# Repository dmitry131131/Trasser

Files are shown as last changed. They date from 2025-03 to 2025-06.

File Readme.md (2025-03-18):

# Трассерная насадка для игры в страйкбол

## Содержание
1. [Цель проекта](#цель-проекта)
2. [Режимы работы](#режимы-работы)
3. [Принцип работы](#принцип-работы)
4. [Необходимые компоненты](#необходимые-компоненты)
5. [Используемые инструменты и станки](#используемые-инструменты-и-станки)
6. [Проблемы и трудности](#проблемы-и-трудности)
7. [Результат](#результат)

## Цель проекта

Разработка и изготовление компактной и надежной трассерной насадки для страйкбольного оружия, которая позволяет визуализировать полет шаров в условиях низкой освещенности. Насадка будет крепиться на ствол оружия на резьбу `M14-` и активироваться при выстреле, подсвечивая траекторию полета шаров с помощью ультрафиолетовых светодиодов. Управление устройством осуществляется на базе микроконтроллера `ATtiny13`, что обеспечивает минимальные габариты и энергопотребление.

## Режимы работы

Трассерная насадка будет иметь `3 режима` работы:
1. Ультрафиолетовая вспышка для подсветки шаров
2. Оранжевая вспышка на срезе ствола для имитации вспышки выстрела
3. Ультрафиолетовая вспышка и имитация вспышки выстрела

## Принцип работы

+ При выстреле страйкбольный шар проходит через ствол, пересекая луч инфракрасного датчика.
+ Датчик передает сигнал на микроконтроллер ATtiny13.
+ Микроконтроллер активирует ультрафиолетовые светодиоды на короткий промежуток времени (0.1 секунду).
+ Светодиоды подсвечивают шар внутри ствола, делая его видимым в темноте.
+ После завершения цикла устройство возвращается в режим ожидания для экономии энергии.

### Идейная схема реализации 

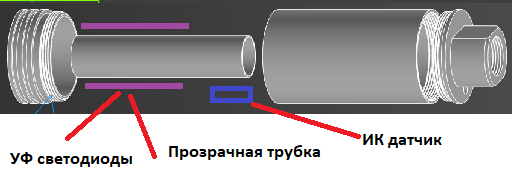
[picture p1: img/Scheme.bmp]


## Необходимые компоненты

Список необходимых компонентов:

### Электроника

| Компонент | Количество |
|---|---|
| Двухсторонний текстолит | 100x100mm |
| Микроконтроллер Attiny13 | 1шт |
| УФ светодиоды формата 5050 | 3шт |
| Оранжевые светодиоды 1206 | 3шт |
| SMD переменный резистор 20k | 1шт |
| SMD резистор 0805 10k | 1шт |
| SMD резистор 0805 1k | 4шт |
| SMD резистор 0805 4k | 1шт |
| SMD резистор 1206 20ОМ | 2шт |
| SMD резистор 1206 150ОМ | 1шт |
| SMD транзистор NPN bc817-40 | 2шт |
| SMD конденсатор 0603 0.1мкФ | 2шт |
| SMD конденсатор 0603 10мкФ | 1шт |
| Инфракрасный фотодиод 3мм | 1шт |
| SMD инфракрасный светодиод | 1шт |
| SMD светодиод 0603 красный | 1шт |
| SMD светодиод 0603 синий | 1шт |
| SMD микросхема TP4056 | 1шт |
| Li-ion аккумулятор 20/20/4мм 3.7В | 1шт |
| USB Type-C разъём | 1шт |
| SMD кнопка | 1шт |

### Корпус

| Компонент | Количество |
|---|---|
| Алюминиевая труба D = 35мм | 60мм |
| Прозрачная трубка D = 15мм | 60мм |
| Винты M3 15мм | 2шт |
| Круг алюминиевый Д16-Т D = 40мм | 60мм |
| Прокладка диаметром 15мм | 1шт |
| Круг алюминиевый D = 20мм | 30мм |

## Используемые инструменты и станки

В этом проекте было задействовано следующее оборудование:

### Для изготовления корпуса

Для изготовления корпуса и переходника `M11/M14-` были использованы:

1. Токарно-винторезный станок `JET GHB-1340A DRO` - для токарных работ

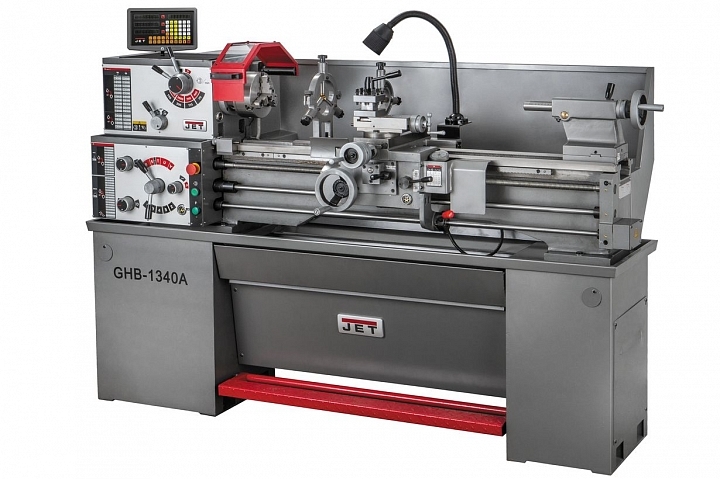
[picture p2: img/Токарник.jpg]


2. Редукторный фрезерно-сверлильный станок `JET JMD-45LPFD` - для фрезерно-сверлильных работ

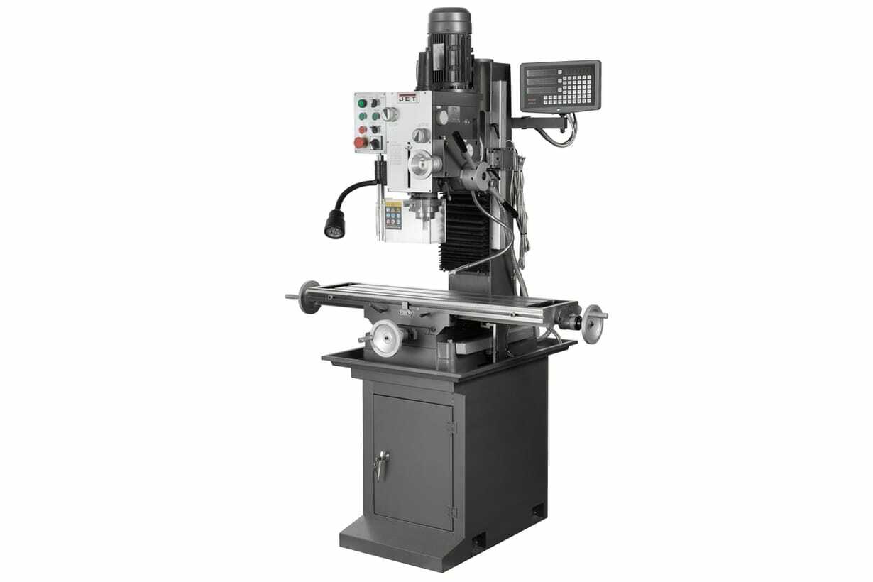
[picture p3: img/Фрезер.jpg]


3. Ленточнопильный станок `JET MBS-1011DAP` - для отрезания заготовок

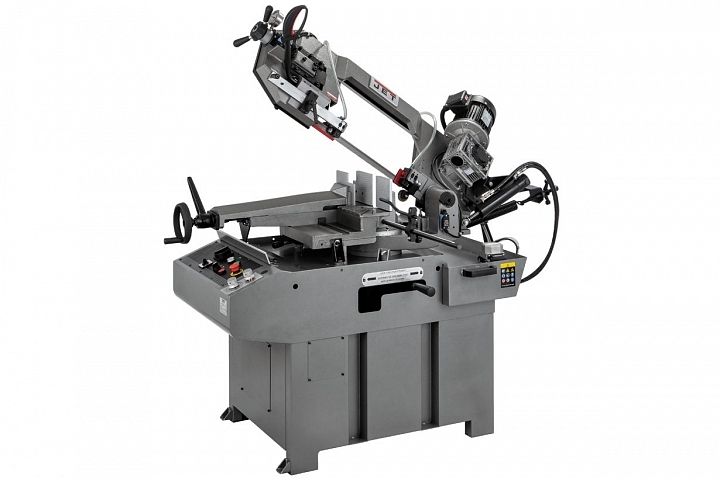
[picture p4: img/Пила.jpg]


### Для изготовления электроники

1. Настольный фрезерно-гравировальный станок `Charly 4U` - для изготовления печатных плат

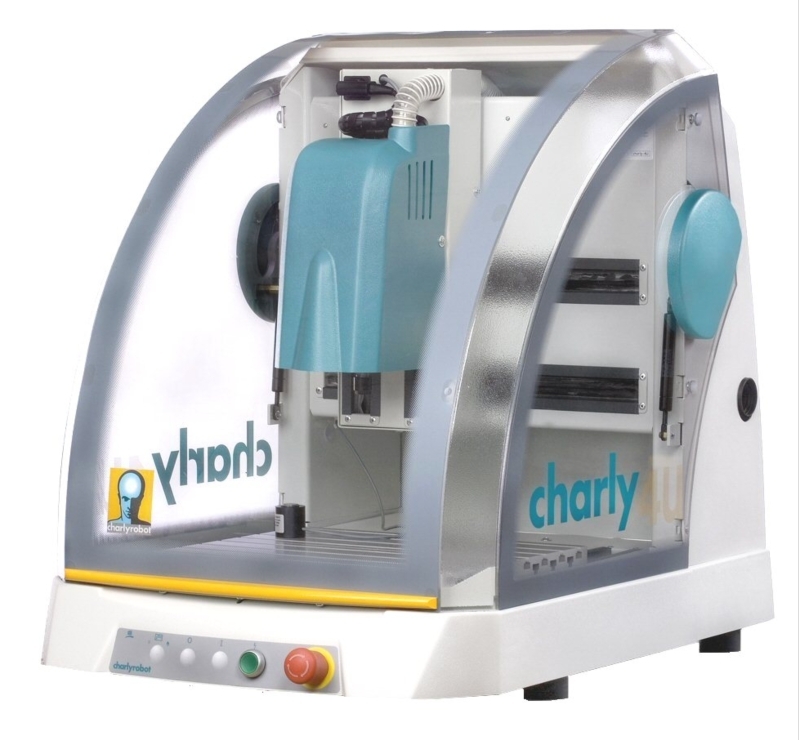
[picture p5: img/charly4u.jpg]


2. Осцилограф цифровой `UNI TREND UTD2102CM` - для диагностики схемы

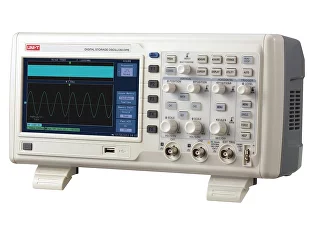
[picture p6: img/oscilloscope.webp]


3. Паяльная станция `Ersa i-CON1` с паяльником `i-TOOL 0IC1100A` - для сборки печатной платы

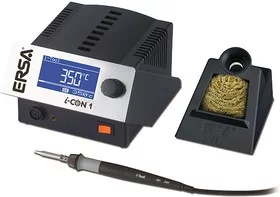
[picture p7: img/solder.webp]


## Процесс изготовления

#### Измерение всех стыковочных параметров, таких как характерные габариты, толщина ствола и параметры резьбы.
  В результате этих измерений было установлено, что в качестве основной резьбы крепления насадки к стволу служит левая резьба стандарта М14 шаг 1мм
  Но в качестве дополнения для использования на стволе пистолета решено было добавить в комплект переходник с M14- на резьбу M11 шаг 1мм, потому что
  именно такую резьбу имеет ствол пистолета.

#### Выбор материалов корпуса, соответствующих требованиям по прочности.
  Материалом корпуса должен был быть прочный металл, который легко выдерживает попадания страйкбольной пули.
  Из вариантов представляется сталь и алюминий. Сталь отбрасывается из-за своей массы и в итоге выбор падает на алюминий.

#### Разработка 3D моделей корпуса и внутреннего каркаса.
  После выбора материала и получения понимания о габаритах разрабатывается 3D модель корпуса в 5 основных деталях:
  + Передняя крышка
  + Основная труба
  + Задняя крышка
  + Внутренняя прозрачная трубка
  + Резьбовой переходник

#### Выбор микроконтроллера, датчиков и дополнительных компонентов.
  Выбор микроконтроллеров на текущий момент велик, но из-за полноты документации и низкой цены выбор пал на Attiny13 архитектуры AVR
  Это компактный 8-ми битный микроконтроллер, работающий на тактовой частоте от 1 до 20 MГц имеющий 6 портов ввода-вывода,
  встроенный аналоговый компаратор, таймер, развитую систему прерываний. Этих возможностей оказывается вполне достаточно для решения задачи.

  Датчик пролета шара основан на инфракрасном фотодиоде, который освещён инфракрасным светодиодом с противоположной стороны и при изменении освещённости
  напряжение на фотодиоде меняется и срабатывает компаратор.

#### Определение оптимальной схемы подключения датчиков.
  Путём экспериментов и постепенного изучения возможностей микроконтроллера была спроектирована и протестирована схема на макетной плате.
  После тестирования сборки можно было приступать к проектированию печатных плат.

#### Разработка принципиальной электрической схемы.
  Из-за необходимости использовать практически везде элементы поверхностного монтажа пришлось немного корректировать принципиальную схему
  исходя из фактических характеристик компонентов, например напряжение открытия транзистора.

#### Разработка и изготовление печатных плат.
  Проектирование печатных плат производилось в программе KICAD.
  После проектирования печатных плат требовалось их изготовить. Для этого использовался фрезерный ЧПУ станок `Charly 4U`.
  К тому же из-за необходимости изготавливать двухсторонние печатные платы пришлось придумывать технологию для соотнесения переходных отверстий.
  Суть метода заключается в том, чтобы просверлить в печатной плате симметрично 4 отверстия под концелярские кнопки и при перевороте платы соотносить эти 4 отверстия.

#### Изготовление и сборка корпуса, финальная сборка.
  После изготовления печатных плат нужно было произвести сборку, распаять все компоненты, прошить микроконтроллер, собрать все в корпус.
  Также необходимо было произвести тесты всех частей устройства.

#### Испытания в лабораторных и боевых условиях.
  Финальной стадией стало тестирование реакции устройства в штатом режиме, тестирование переключения режимов, тестирование модуля зарядки аккумулятора,
  а также тестирование непосредственно в работе.

## Проблемы и трудности

В процессе изготовления возникли некоторые трудности, которые пришлось преодолеть

### Неисправность токарного станка

Первой проблемой, которую необходимо было решить это неисправность ходового винта токарного станка. Так как мне было необходимо нарезать нестандартную резьбу, мне нужен был функционирующий ходовой винт на токарном станке, но он был повреждён предыдущими пользователями(срезаны срезные шпильки крепления).

Для решения этой проблемы с помощью другого токарного станка(без возможности нарезания резьбы) `MetalMaster MML2870M` были выточены новые срезные шпильки из латуни и функционирование токарного станка `JET GHB-1340A DRO` было восстановлено.

### Необходимость нарезания резьбы по алюминию

Процесс нарезания резьбы по алюминию представляет некоторую трудность из-за пластичности металла, поэтому если использовать универсальные резьбонарезные пластинки, то резьба получается рваная, вот пример:

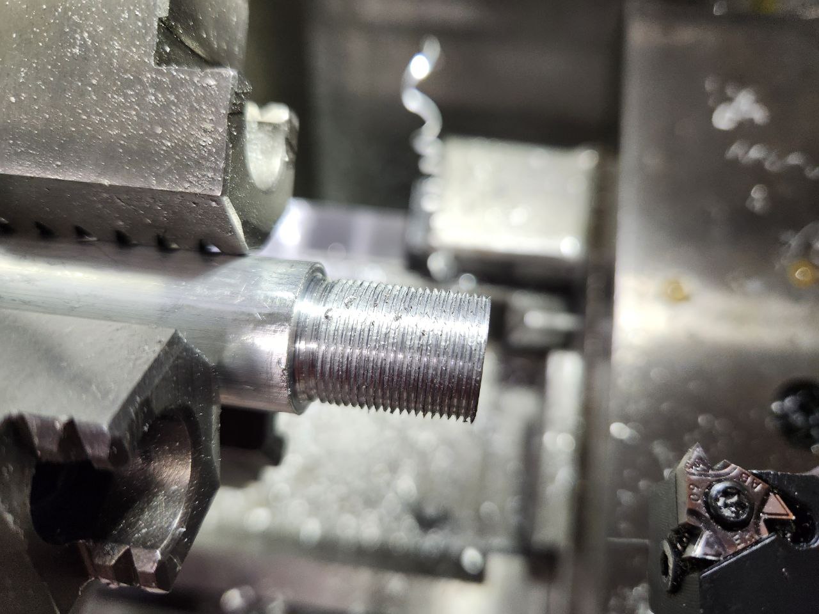
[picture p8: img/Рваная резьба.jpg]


Поэтому были куплены специальные резьбонарезные пластинки по алюминию(сплав К15) и результат был сильно улучшен, вот пример:

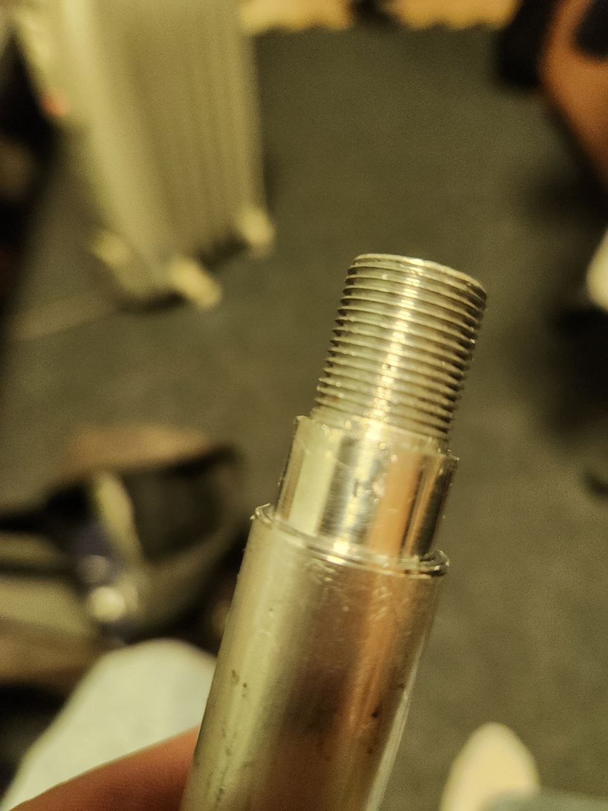
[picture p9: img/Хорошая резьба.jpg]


### Необходимость создания двухсторонних печатных плат

В виду компактности печатной платы имеется необходимость размещения компонентов и дорожек на двух поверхностях печатной платы.
Но на фрезерном станке удобно производить односторонние печальные платы, в результате чего мною использована технология по точному совпадению печатной платы при перевороте по 4 точкам, чтобы добиться соосности переходных отверстий. 

`Процесс фрезеровки:`

<video width="600" height="800" controls>
  <source src="img/Фрезировка.mp4" type="video/mp4">
</video>

Фрезировка

### Несовпадение габаритов фотодиода

Габариты фотодиода оказались больше ожидаемых, в результате чего он не помещался под прозрачной трубкой.

Пришлось с помощью гравера уменьшить его габариты:

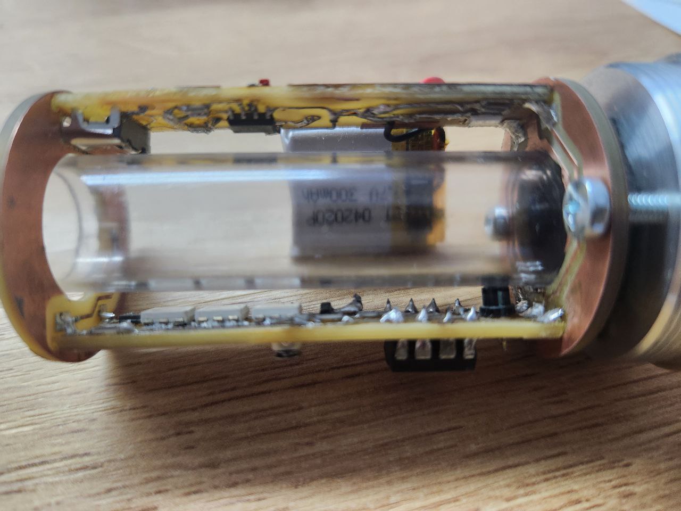
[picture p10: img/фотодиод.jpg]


## Тестирование

После предварительной сборки устройства без системы зарядки аккумулятора был произведён тест на срабатывание датчика и включение вспышки.
Также был произведён тест смены режимов работы(посредством удержания кнопки на корпусе в течение 1 секунды). 
Индикатором смены режима работы служит кратковременная вспышка на торце насадки.

### Срабатывание датчика в замедленной съёмке
<video width="600" height="800" controls>
  <source src="img/Слоумо.mp4" type="video/mp4">
</video>

Срабатывание датчика в замедленной съёмке

Затем был произведён тест работы модуля зарядки. При зарядке загорается индикация и идет процесс зарядки. 

### Работа индикации заряда аккумулятора
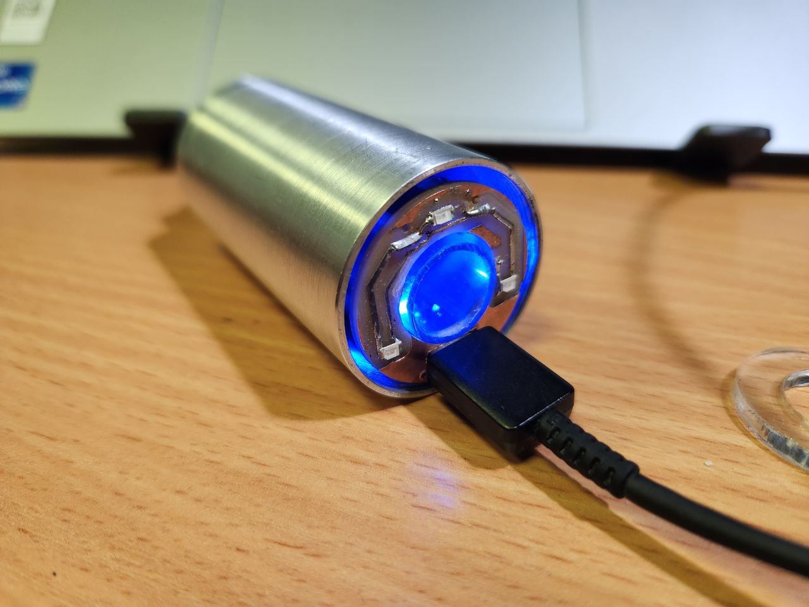
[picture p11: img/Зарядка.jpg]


Затем после финальной сборки изделия был произведён финальный тест непосредственно в условиях эксплуатации.

### Работа насадки
<video width="600" height="800" controls>
  <source src="img/Выстрел.mp4" type="video/mp4">
</video>

Работа насадки

## Результат

В результате получилась полностью рабочая и готовая к эксплуатации трассерная насадка.

Но в процессе тестирования была выявлена одна незначительная ошибка:

При сборке были перепутаны красный и синий светодиоды в модуле зарядки. 
И теперь в процессе зарядки горит синий светодиод, а индикатор заряженного аккумулятора горит красным цветом.

Но эта ошибка не влияет на основную задачу насадки.

| | | |
| --- | --- | --- |
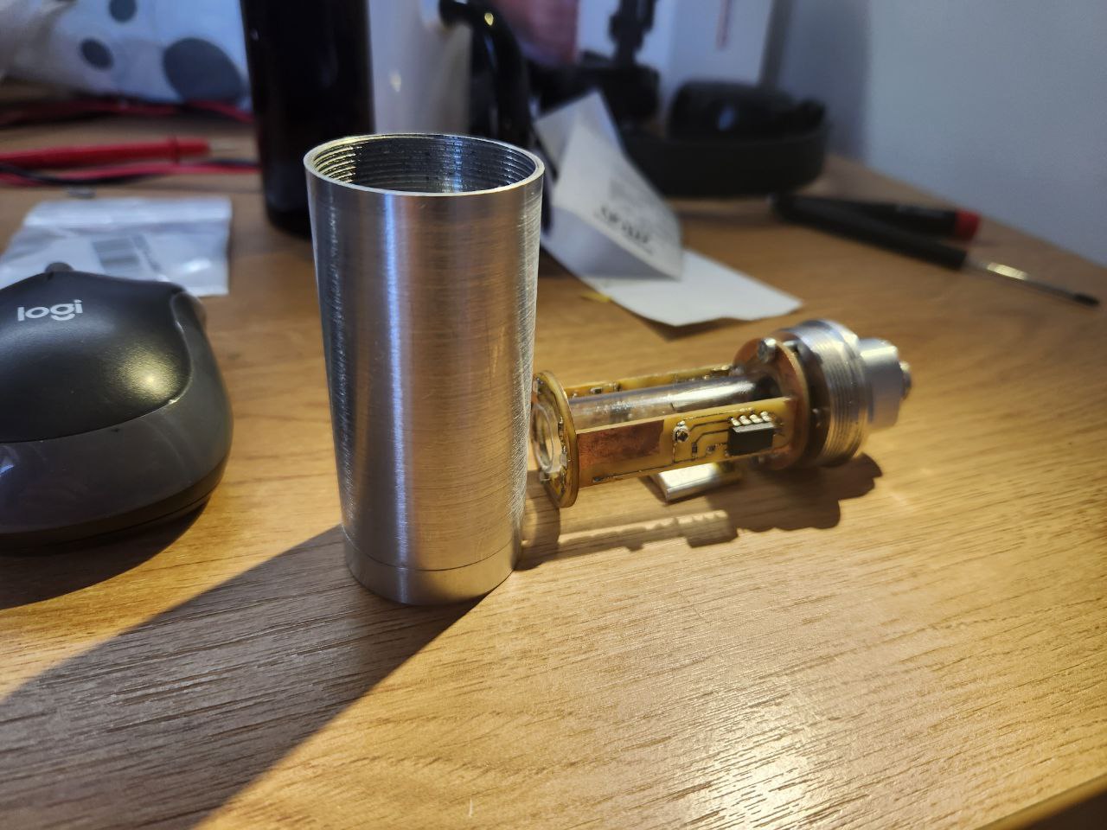
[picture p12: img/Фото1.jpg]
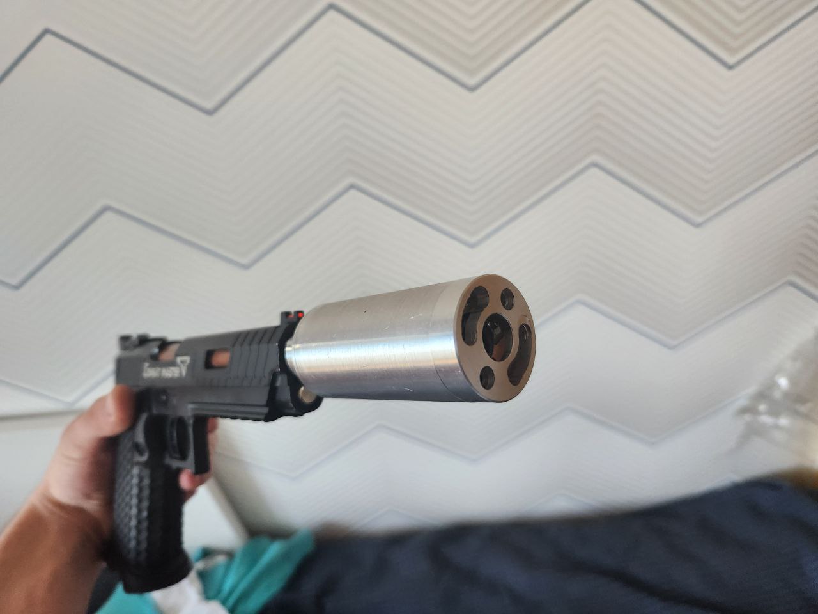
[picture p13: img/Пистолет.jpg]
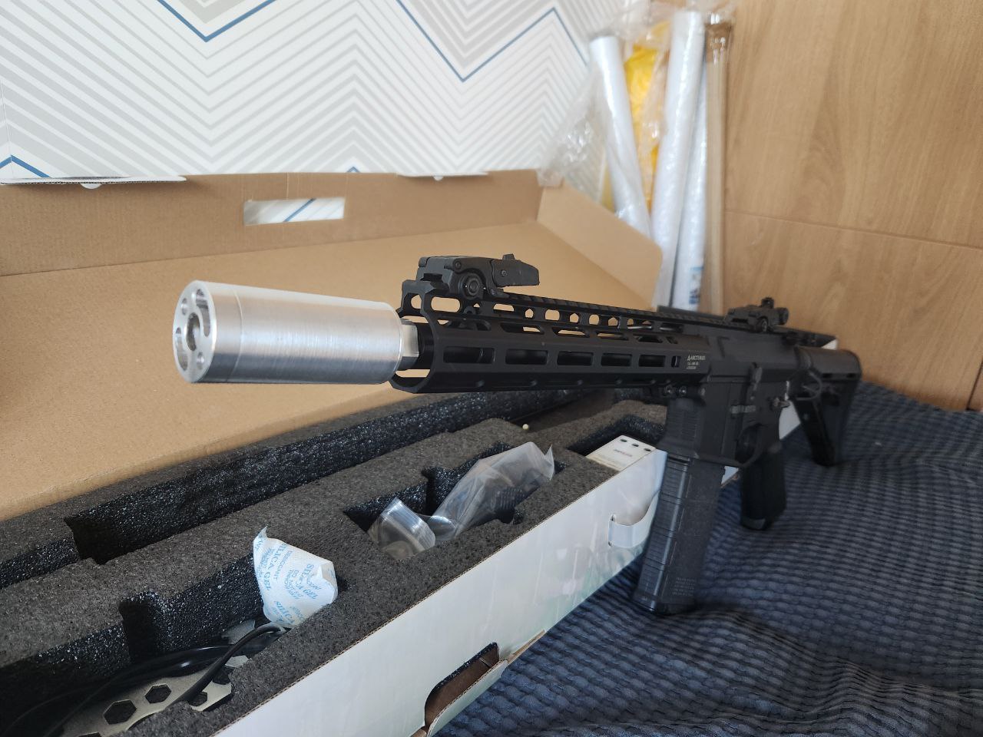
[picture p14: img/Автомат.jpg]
|  |  |

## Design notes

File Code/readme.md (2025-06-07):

# Прошивка к Трассерной насадке

Эта прошивка подходит для трассерной насадки из этого репозитория.
**Целевой микроконтроллер:** Attiny13 (Архитектура AVR)
**Программатор:** USBASP
**Компилятор:** avr-gcc

## Сборка и прошивка

Для сборки проекта выполните следующую команду из директории, содержащей makefile:

```bash
    make hexing
```

Затем подключите программатор USBASP к микроконтроллеру согласно схеме подключения:

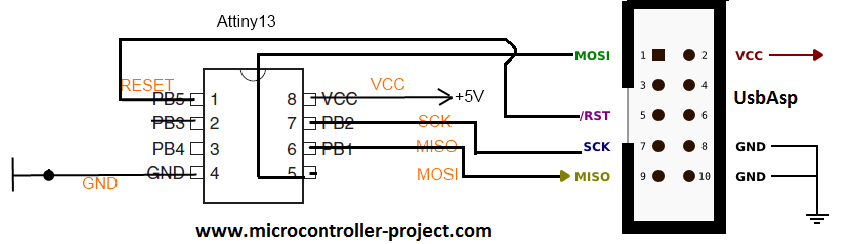
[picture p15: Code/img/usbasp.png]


И выполните команду:

```bash
    make flash
```

После чего выполните команду для правильной настройки "фьюзов" микроконтроллера:

```bash
    make write_lfuse_high_frequency
```

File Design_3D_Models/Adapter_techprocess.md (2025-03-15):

# Техпроцесс производства переходника

## Токарные работы (первая стадия)

### Приготовления

1. Установить заготовку в патрон JET
2. Установить и отцентровать 3 резца:
    + Правый прохдной
    + Отрезной
    + Малый резбонарезной
3. Установить и отцентровать сверло на 8.5 в заднюю бабку   
4. Установить коробку подач на 1мм резьбу и включить 450 об\мин

### Изготовление

1. Обтачиваем цилиндр длиной 25-30мм и диаметром 17.2мм
2. Справа обтачиваем цилиндр длиной 10-12мм и диаметром (13.85 +- 0.05)мм (точно)
3. Слева обтачиваем цилиндр длиной 8-10мм и диаметром (10.85 +- 0.05)мм (точно)
4. При этом оставляем цилиндрическую полосу длинной 1.5мм
5. Подводим сверло и просверливаем отверстие
6. Переводим станок в режим нарезки резьбы, ставим 70-190 об\мин и устанавливаем резец по уровню
7. Подводим резец в начало и протачиваем вглубь на 1.2мм (по диаметру)
8. Включаем маточную гайку и режем резьб за 1 проход.
9. Переключаемся на отрезной резец и обрезаем резьбовую часть до (9.5 =- 0.5)мм 
10. Отрезаем деталь слева, так чтобы длина левой части было не менее 8мм

## Нарезание резьбы (вторая стадия)

1. Берём оснастку на 14мм и зажимаем деталь в тисках
2. Берём плашку на М11x1(правая) и нарезаем резьбу 

## Токарные работы (третья стадия)

1. Берём оснастку на 14мм, зажимаем деталь в патроне Metal Master
2. Берём проходной резец и отрезаем резьбу до длины 5мм
3. Обтачиваем правую часть резьбы до диаметра глубины резьбы (9.8мм)
4. С помощью отрезного резца делаем фаску
5. Берём оснастку 11мм, зажимаем деталь в этом же патроне
6. С помощью отрезного резца делаем фаску

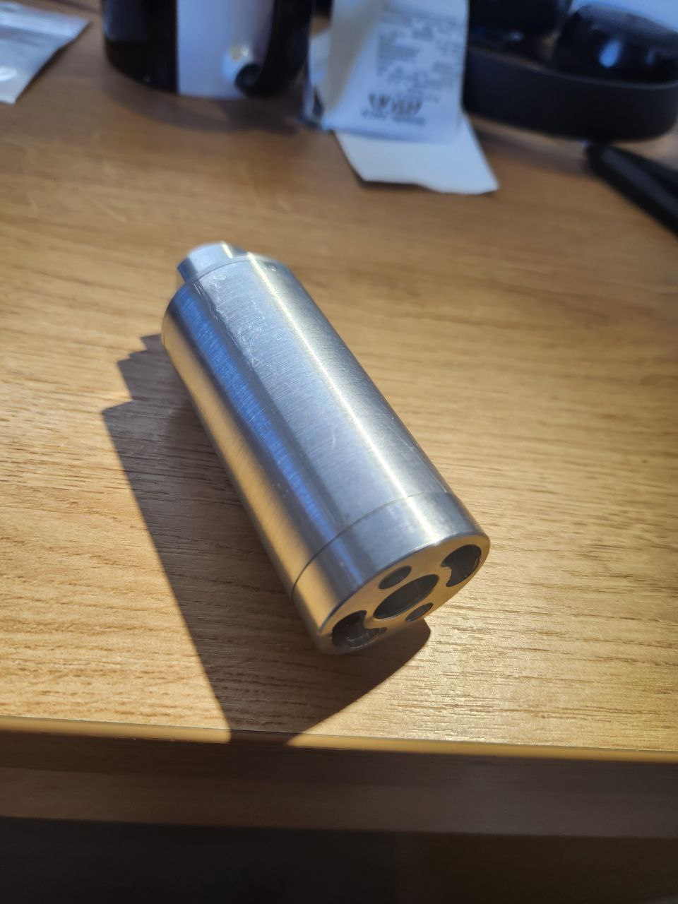
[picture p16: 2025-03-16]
img/Фото2.jpg

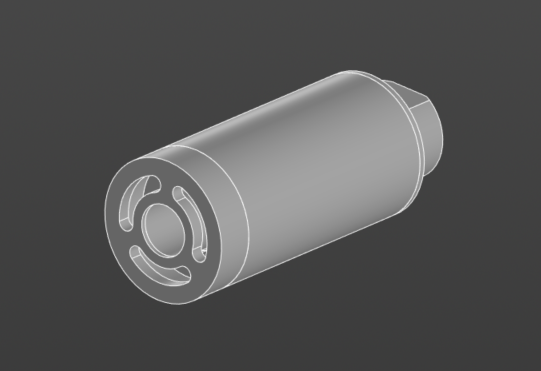
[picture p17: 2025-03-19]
img/Фронт.PNG

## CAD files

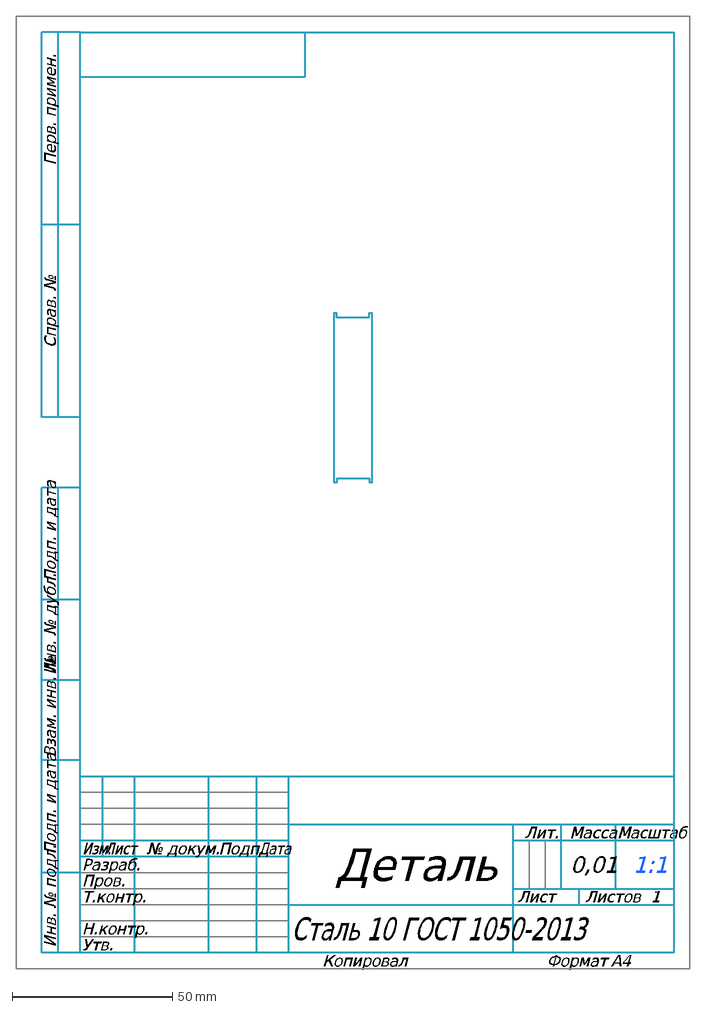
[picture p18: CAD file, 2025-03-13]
Design_3D_Models/Контуры плат/dxf/Основная часть платы.dxf
Масса
Масштаб
Изм.
Лист
№ докум.
Подп.
Дата
Лит.
Разраб.
Пров.
Т.контр.
Листов
Н.контр.
Утв.
1:1
1
Деталь
Сталь 10 ГОСТ 1050-2013
0,01
Инв. № подл.
Подп. и дата
Взам. инв. №
Инв. № дубл.
Справ. №
Перв. примен.
Копировал
Формат
A4

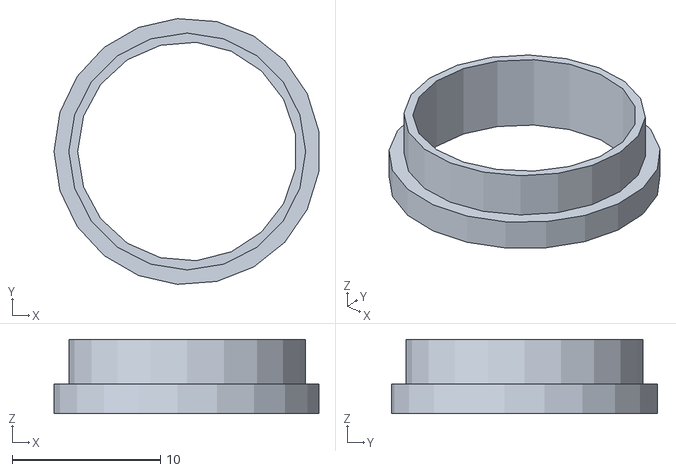
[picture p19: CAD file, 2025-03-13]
Design_3D_Models/Механическая часть/3д модели/Прокладка.stl
17.9 x 17.9 x 5.00

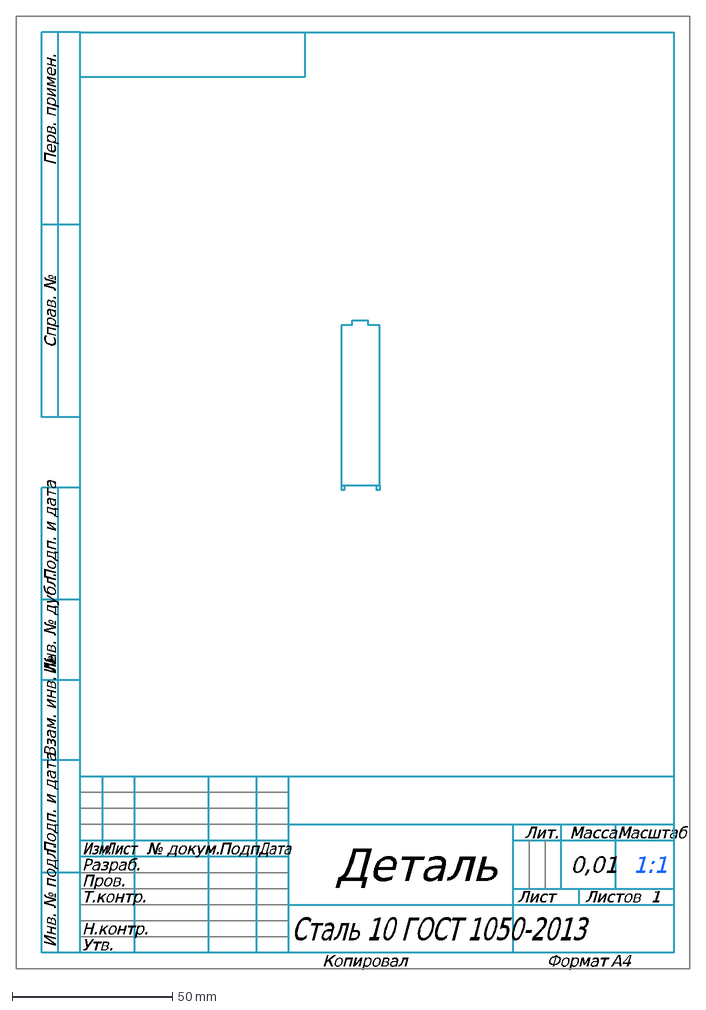
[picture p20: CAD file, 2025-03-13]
Design_3D_Models/Контуры плат/dxf/Аккумуляторная часть платы.dxf
Масса
Масштаб
Изм.
Лист
№ докум.
Подп.
Дата
Лит.
Разраб.
Пров.
Т.контр.
Листов
Н.контр.
Утв.
1:1
1
Деталь
Сталь 10 ГОСТ 1050-2013
0,01
Инв. № подл.
Подп. и дата
Взам. инв. №
Инв. № дубл.
Справ. №
Перв. примен.
Копировал
Формат
A4

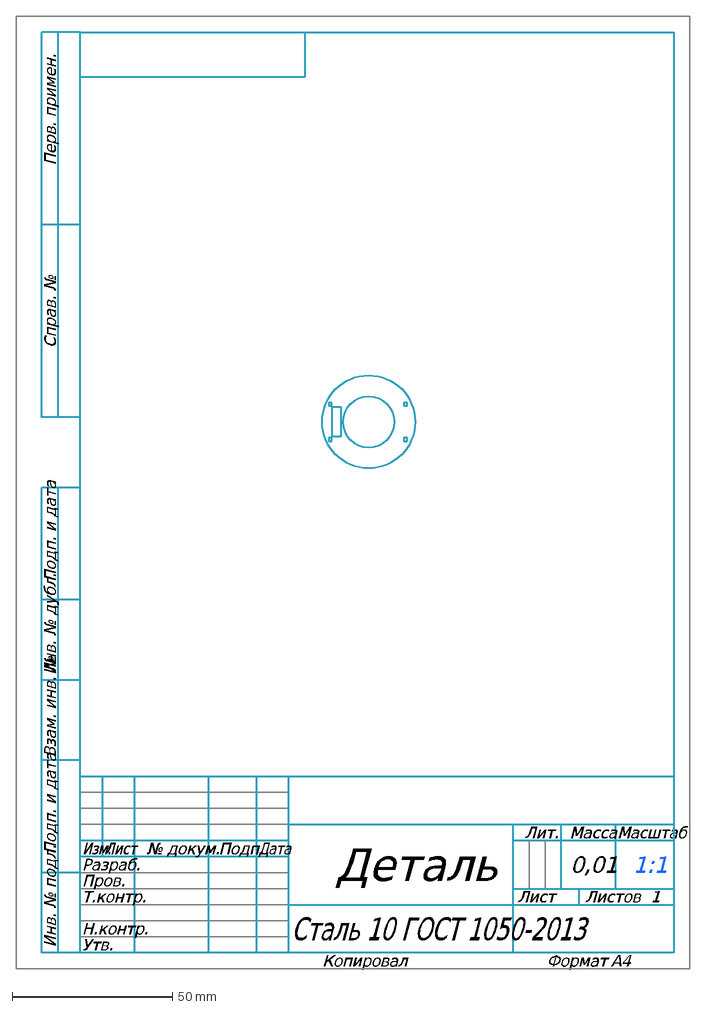
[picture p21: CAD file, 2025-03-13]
Design_3D_Models/Контуры плат/dxf/Фронтальная часть платы.dxf
Масса
Масштаб
Изм.
Лист
№ докум.
Подп.
Дата
Лит.
Разраб.
Пров.
Т.контр.
Листов
Н.контр.
Утв.
1:1
1
Деталь
Сталь 10 ГОСТ 1050-2013
0,01
Инв. № подл.
Подп. и дата
Взам. инв. №
Инв. № дубл.
Справ. №
Перв. примен.
Копировал
Формат
A4

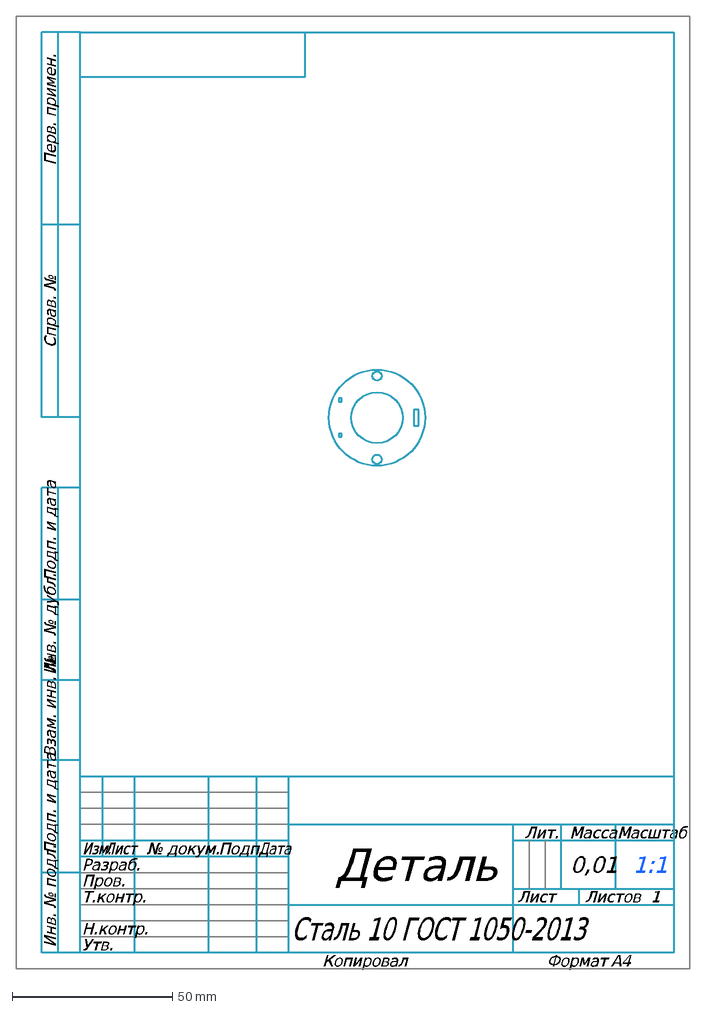
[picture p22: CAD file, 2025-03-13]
Design_3D_Models/Контуры плат/dxf/Задняя часть платы.dxf
Масса
Масштаб
Изм.
Лист
№ докум.
Подп.
Дата
Лит.
Разраб.
Пров.
Т.контр.
Листов
Н.контр.
Утв.
1:1
1
Деталь
Сталь 10 ГОСТ 1050-2013
0,01
Инв. № подл.
Подп. и дата
Взам. инв. №
Инв. № дубл.
Справ. №
Перв. примен.
Копировал
Формат
A4

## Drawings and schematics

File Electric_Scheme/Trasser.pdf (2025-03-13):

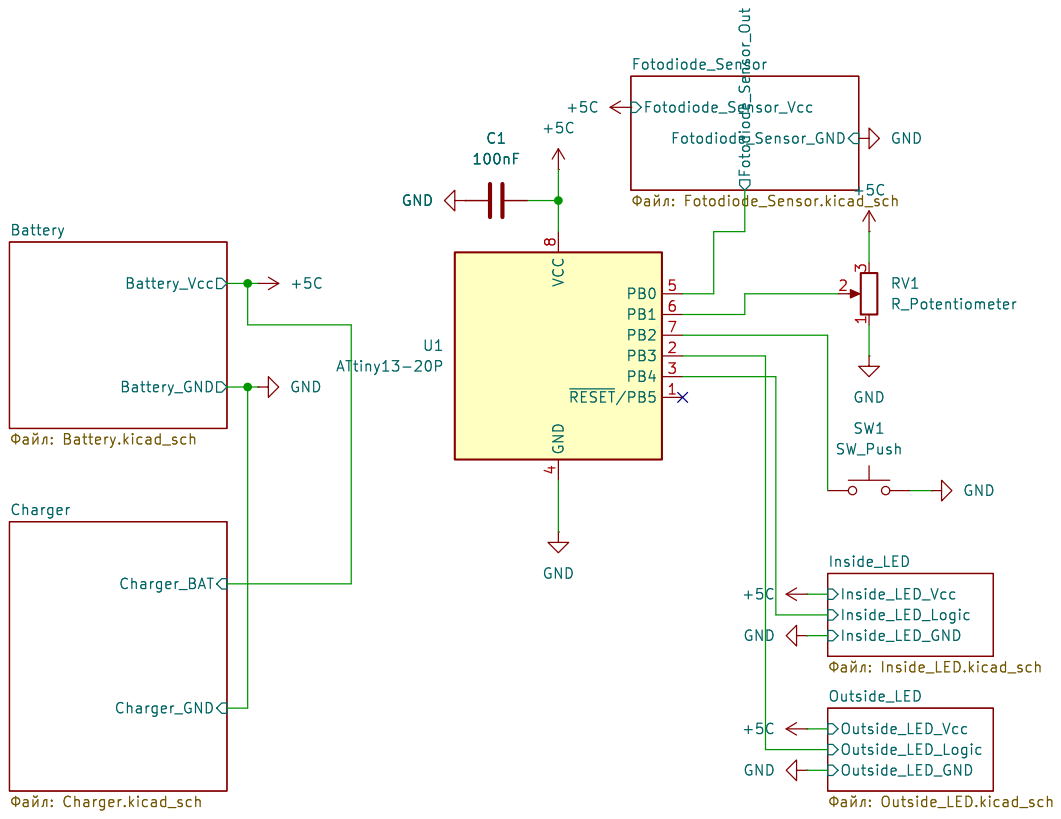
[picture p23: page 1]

Id: 1/6 Title: File: Trasser.kicad_sch Sheet: / Charger_BAT

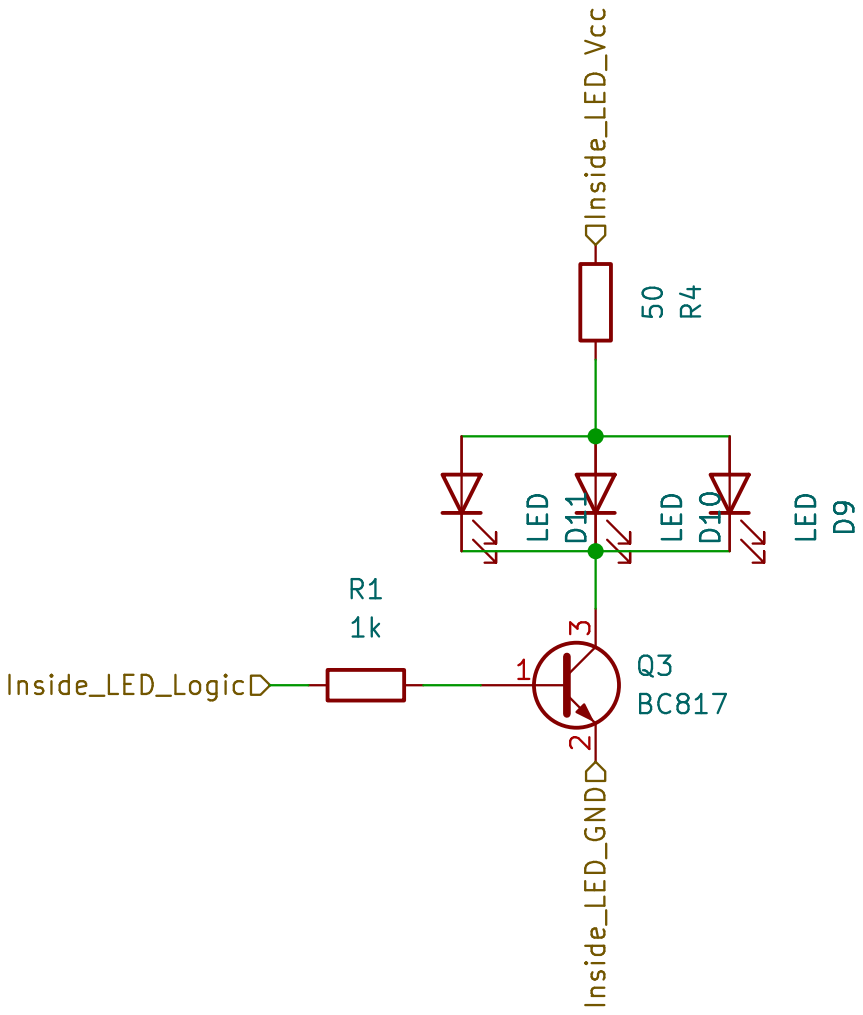
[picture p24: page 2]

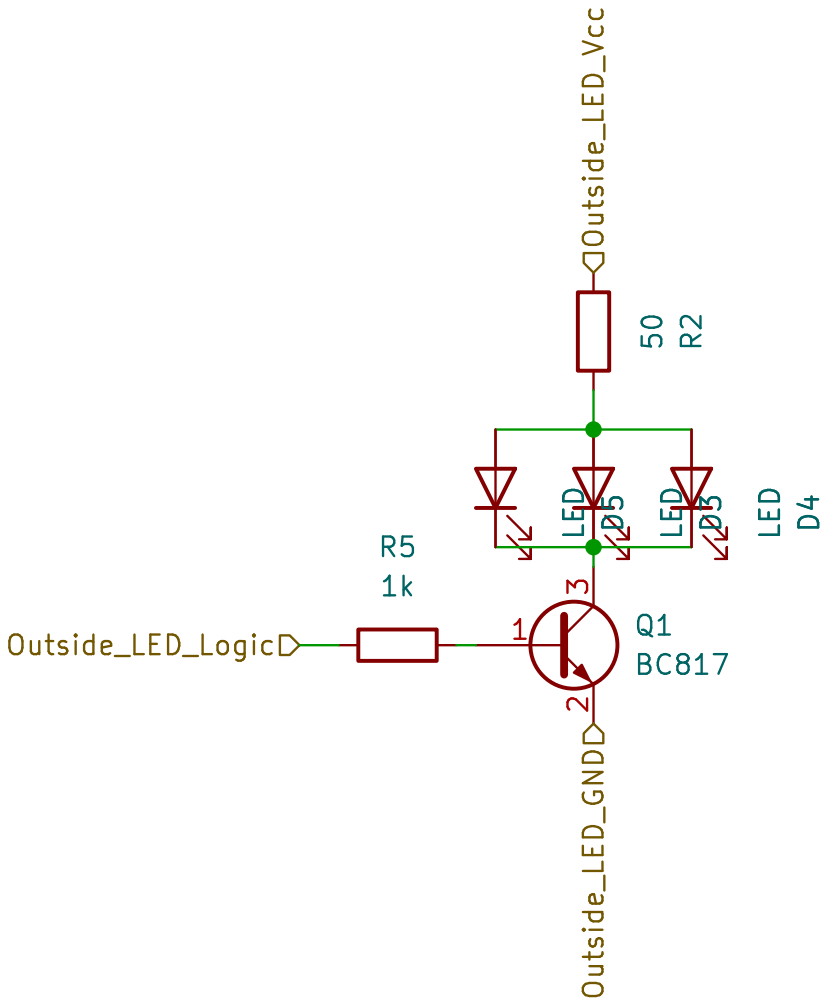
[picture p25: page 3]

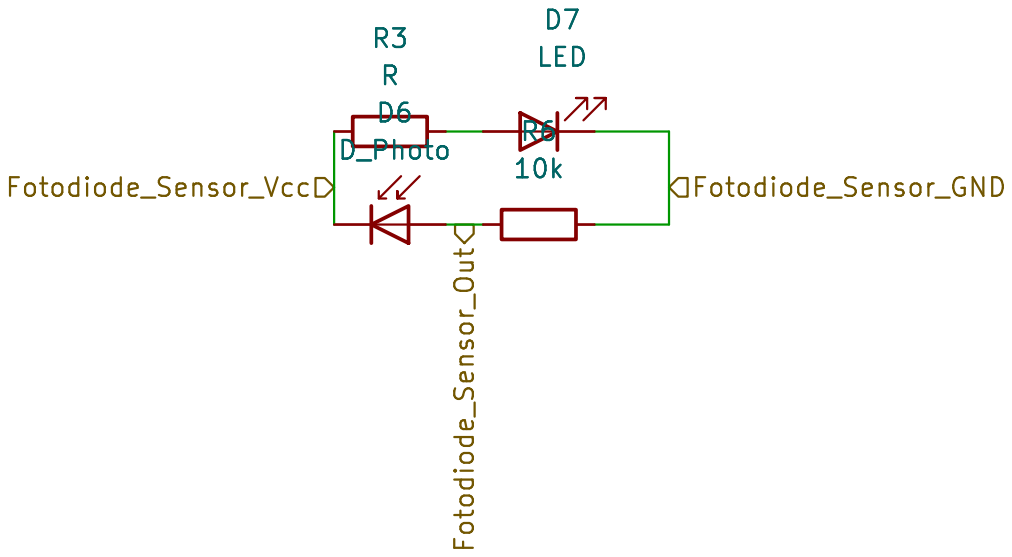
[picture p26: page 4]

Id: 4/6 Title: File: Fotodiode_Sensor.kicad_sch Sheet: /Fotodiode_Sensor/

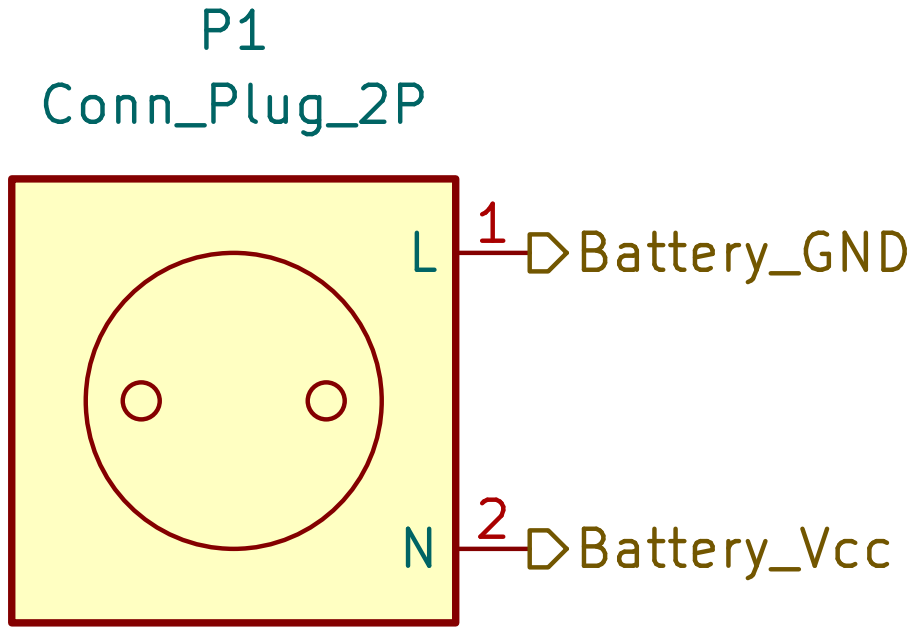
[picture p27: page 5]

Id: 5/6 Title: File: Battery.kicad_sch Sheet: /Battery/

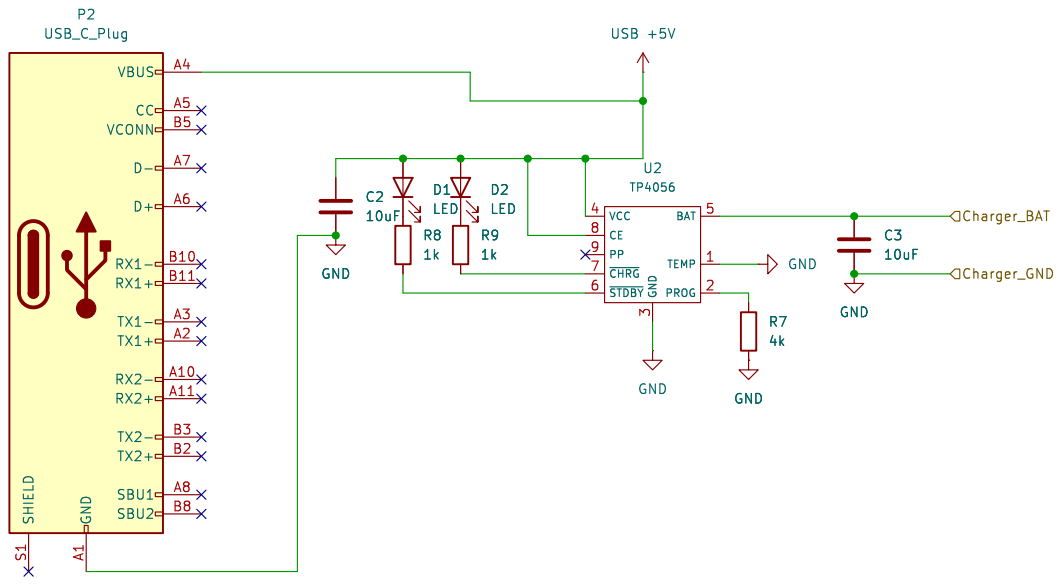
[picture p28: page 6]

Id: 6/6 Title: File: Charger.kicad_sch Sheet: /Charger/

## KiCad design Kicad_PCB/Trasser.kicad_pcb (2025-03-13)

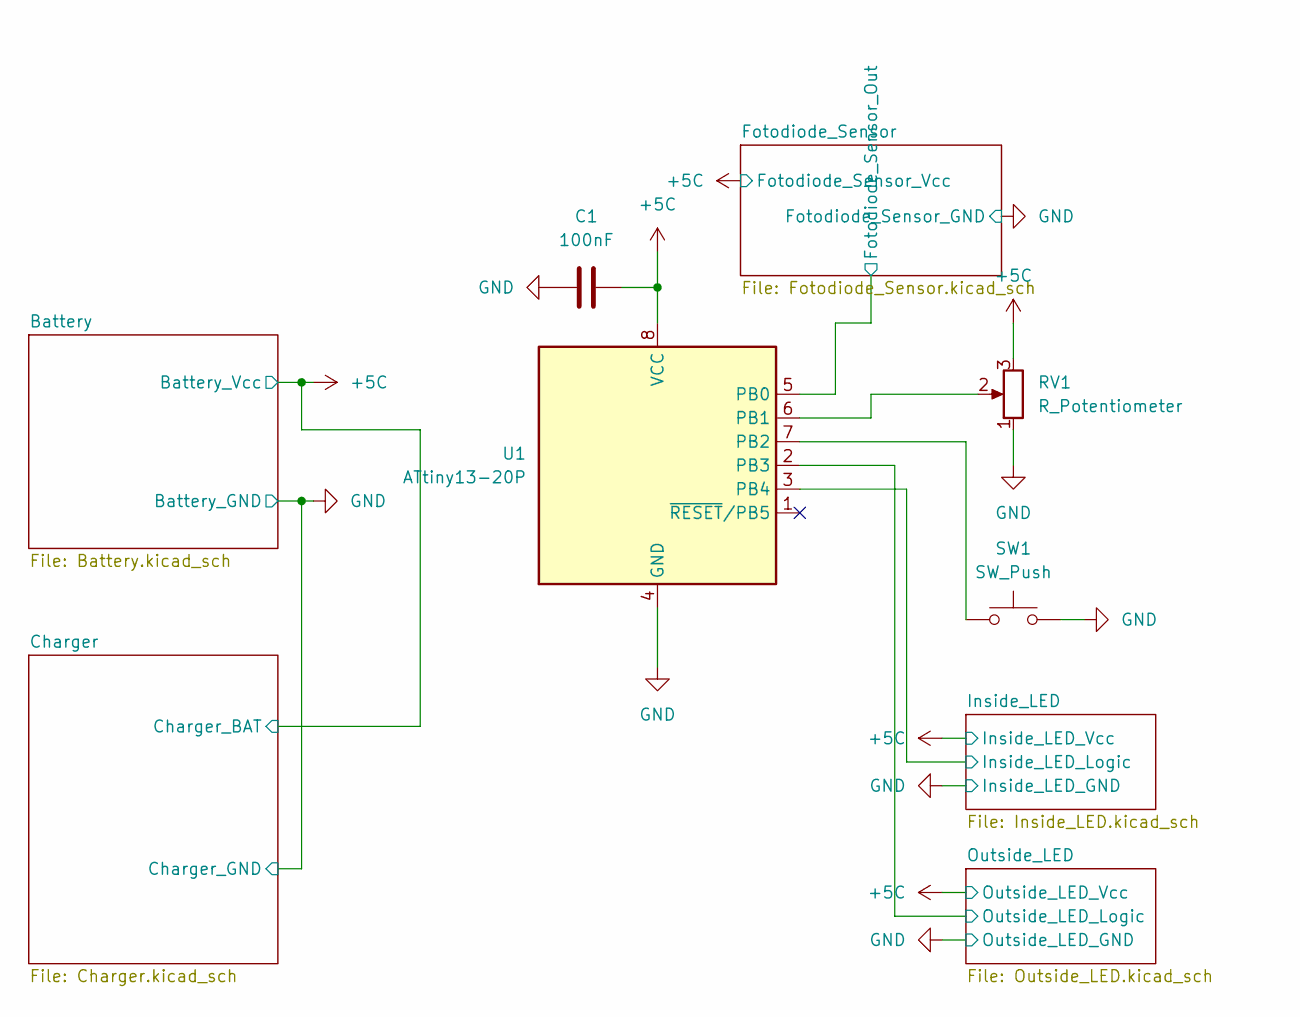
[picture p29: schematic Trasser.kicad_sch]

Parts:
C1: 100nF; C_0603_1608Metric_Pad1.08x0.95mm_HandSolder
RV1: R_Potentiometer; Potentiometer_Bourns_TC33X_Vertical
SW1: SW_Push; SW_SPST_EVQPE1
U1: ATtiny13-20P; DIP-8_W7.62mm

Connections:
+5C: C1.2, RV1.3, U1.8 (VCC); also elsewhere on the board
/Fotodiode_Sensor/Fotodiode_Sensor_Out: U1.5 (PB0); also elsewhere on the board
/Inside_LED/Inside_LED_Logic: U1.3 (PB4); also elsewhere on the board
/Outside_LED/Outside_LED_Logic: U1.2 (PB3); also elsewhere on the board
GND: C1.1, RV1.1, SW1.2, U1.4 (GND); also elsewhere on the board
unnamed: RV1.2, U1.6 (PB1)
unnamed: SW1.1, U1.7 (PB2)

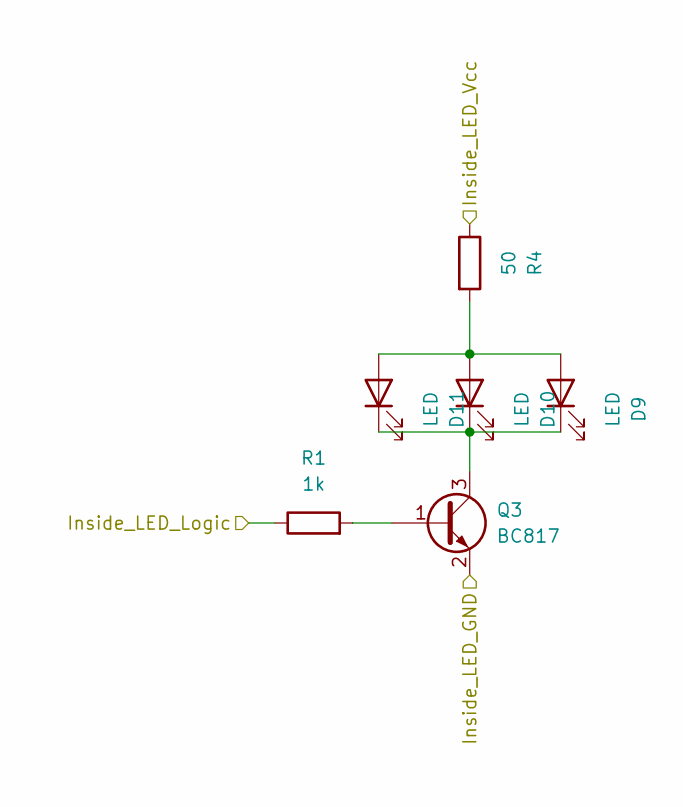
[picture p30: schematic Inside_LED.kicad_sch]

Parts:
D9, D10, D11: LED; LED_5050
Q3: BC817; SOT-23
R1: 1k; R_0603_1608Metric
R4: 50; R_1206_3216Metric

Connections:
+5C: R4.1; also elsewhere on the board
/Inside_LED/Inside_LED_Logic: R1.1; also elsewhere on the board
GND: Q3.2 (E); also elsewhere on the board
unnamed: D9.2 (A), D10.2 (A), D11.2 (A), R4.2
unnamed: D9.1 (K), D10.1 (K), D11.1 (K), Q3.3 (C)
unnamed: Q3.1 (B), R1.2

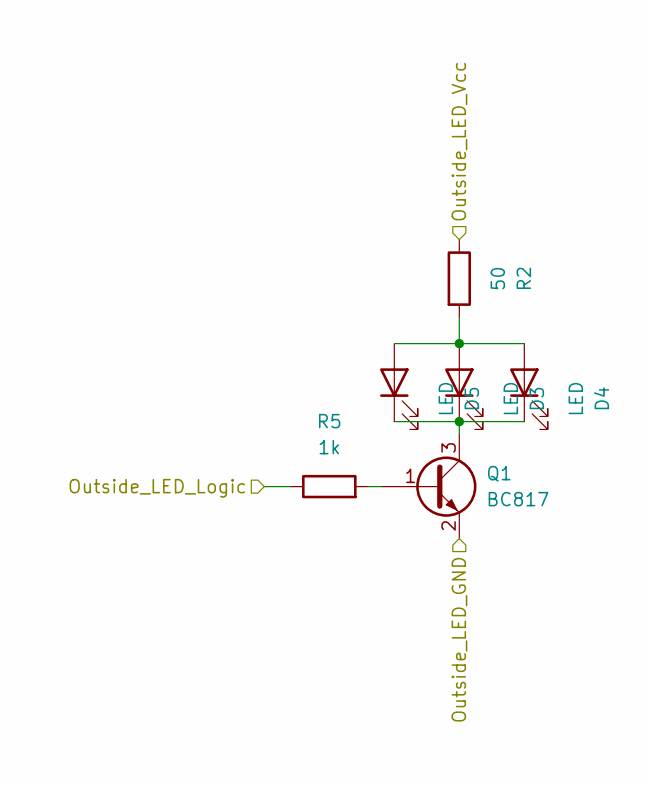
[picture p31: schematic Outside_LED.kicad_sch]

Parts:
D3, D4, D5: LED; LED_1206_3216Metric
Q1: BC817; SOT-23
R2: 50; R_1206_3216Metric
R5: 1k; R_0603_1608Metric

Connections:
+5C: R2.1; also elsewhere on the board
/Outside_LED/Outside_LED_Logic: R5.1; also elsewhere on the board
GND: Q1.2 (E); also elsewhere on the board
unnamed: D3.2 (A), D4.2 (A), D5.2 (A), R2.2
unnamed: D3.1 (K), D4.1 (K), D5.1 (K), Q1.3 (C)
unnamed: Q1.1 (B), R5.2

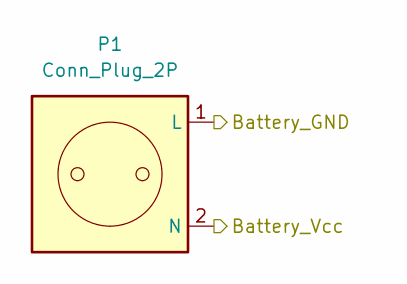
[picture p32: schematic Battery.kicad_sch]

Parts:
P1: Conn_Plug_2P; PinSocket_1x02_P2.00mm_Horizontal

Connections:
+5C: P1.2 (N); also elsewhere on the board
GND: P1.1 (L); also elsewhere on the board

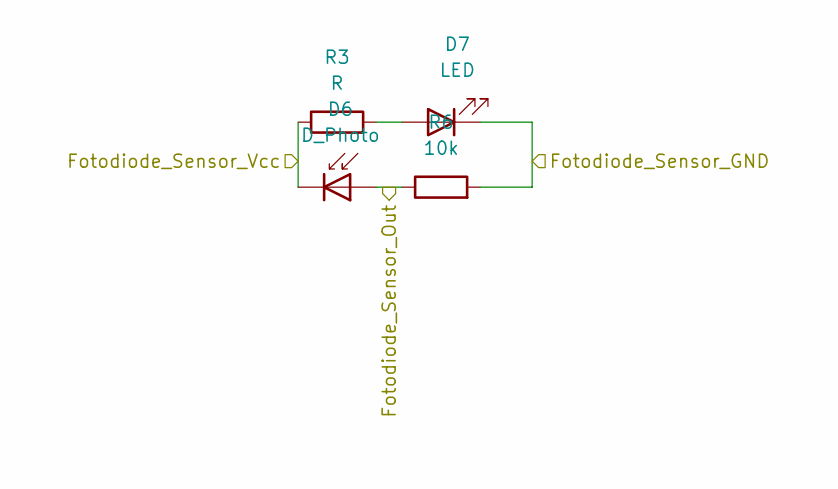
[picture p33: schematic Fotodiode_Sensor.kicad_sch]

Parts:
D6: D_Photo; LED_D3.0mm
D7: LED; LED_PLCC_2835_Handsoldering
R3: R; R_1206_3216Metric
R6: 10k; R_0805_2012Metric_Pad1.20x1.40mm_HandSolder

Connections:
+5C: D6.1 (K), R3.1; also elsewhere on the board
/Fotodiode_Sensor/Fotodiode_Sensor_Out: D6.2 (A), R6.1; also elsewhere on the board
GND: D7.1 (K), R6.2; also elsewhere on the board
unnamed: D7.2 (A), R3.2

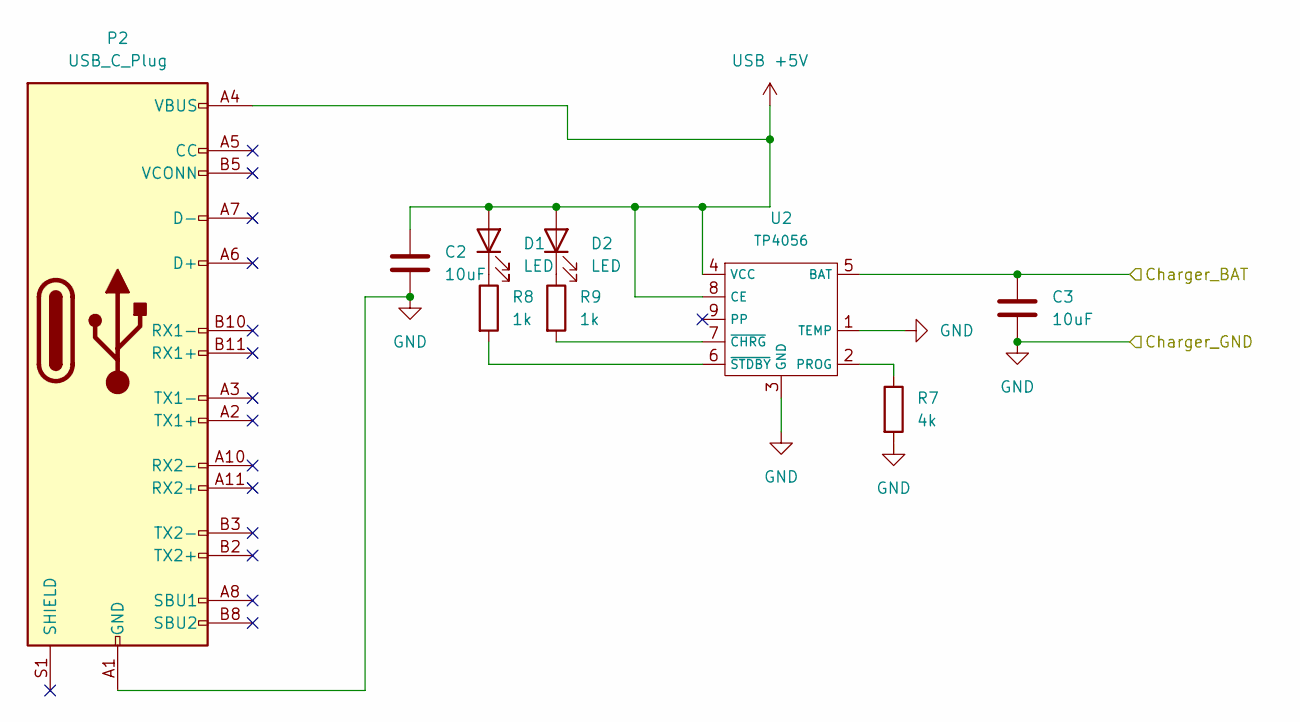
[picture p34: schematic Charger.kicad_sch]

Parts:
C2, C3: 10uF; C_0603_1608Metric_Pad1.08x0.95mm_HandSolder
D1, D2: LED; LED_0402_1005Metric
P2: USB_C_Plug; USB_C_POWER_ONLY
R7: 4k; R_0603_1608Metric_Pad0.98x0.95mm_HandSolder
R8, R9: 1k; R_0805_2012Metric_Pad1.20x1.40mm_HandSolder
U2: TP4056; SOIC-8-1EP_3.9x4.9mm_P1.27mm_EP2.29x3mm

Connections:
+5C: C3.1, U2.5 (BAT); also elsewhere on the board
GND: C2.2, C3.2, P2.A1 (GND), P2.A12 (GND), P2.B1 (GND), P2.B12 (GND), R7.2, U2.1 (TEMP), U2.3 (GND); also elsewhere on the board
unnamed: D1.1 (K), R8.1
unnamed: D2.1 (K), R9.1
unnamed: R7.1, U2.2 (PROG)
unnamed: R9.2, U2.7 (~CHRG)
unnamed: R8.2, U2.6 (~STDBY)
USB +5V: C2.1, D1.2 (A), D2.2 (A), P2.A4 (VBUS), P2.A9 (VBUS), P2.B4 (VBUS), P2.B9 (VBUS), U2.4 (VCC), U2.8 (CE)

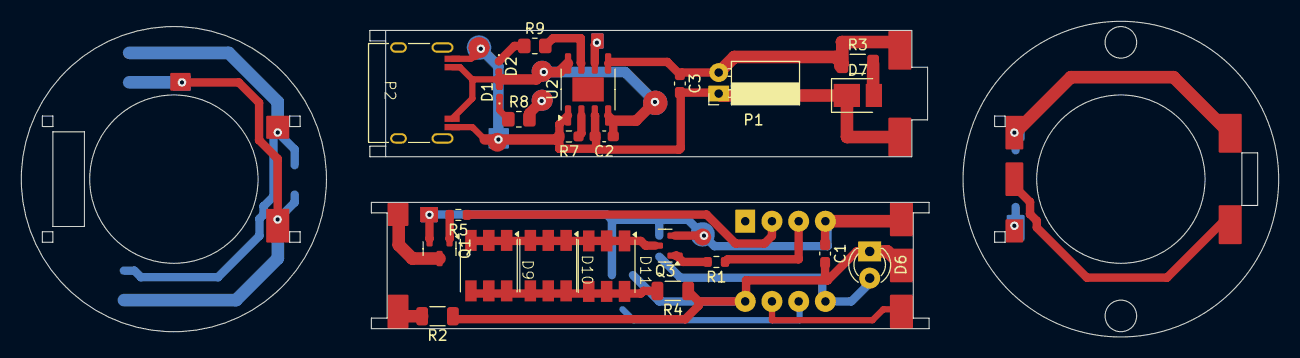
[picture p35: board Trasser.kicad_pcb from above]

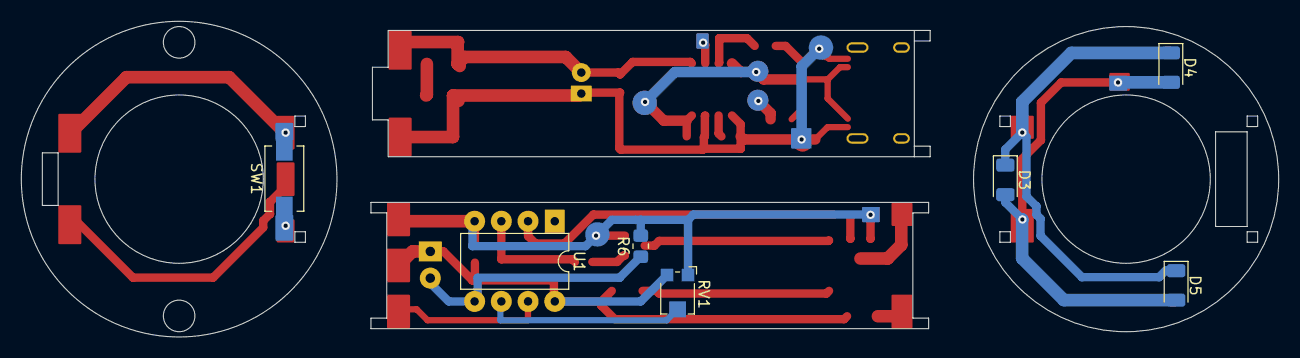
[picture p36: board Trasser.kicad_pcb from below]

Board: 2 copper layers, 119.5 x 30.0 mm, 30 parts (7 on the bottom side), 20 nets.

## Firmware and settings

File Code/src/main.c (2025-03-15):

#include "utils.h"
#include "init.h"
#include "custom_delay.h"

// Enum с режимами работы насадки
volatile enum Mode {
    ONLY_INSIDE,
    ONLY_OUTSIDE,
    INSIDE_AND_OUTSIDE,
} global_mode = ONLY_INSIDE;

// Функция генерации вспышки от выстрела
void blink_led(enum Mode mode) {
    switch (mode)
    {
    case ONLY_INSIDE:
        Inside_LED_On();
        break;
    case ONLY_OUTSIDE:
        Outside_LED_On();
        break;
    case INSIDE_AND_OUTSIDE:
        Inside_LED_On();
        Outside_LED_On();
    break;
    }

    delay_x_0_1_sec(1);

    switch (mode)
    {
    case ONLY_INSIDE:
        Inside_LED_Off();
        break;
    case ONLY_OUTSIDE:
        Outside_LED_Off();
        break;
    case INSIDE_AND_OUTSIDE:
        Inside_LED_Off();
        Outside_LED_Off();
    break;
    }
}

// Прерывание по изменению уровня на PCINT2
// Переключение режима работы насадки
ISR(PCINT0_vect) {
    if (PINB & (1 << PB2)) return;

    delay_x_0_1_sec(6);

    if (PINB & (1 << PB2)) return;

    switch (global_mode)
    {
    case ONLY_INSIDE:
        global_mode = ONLY_OUTSIDE;
        break;
    case ONLY_OUTSIDE:
        global_mode = INSIDE_AND_OUTSIDE;
        break;
    case INSIDE_AND_OUTSIDE:
        global_mode = ONLY_INSIDE;
        break;
    }
    small_outside_blink();
}

// Прерывание по компаратору
// Срабатывание датчика 
ISR(ANA_COMP_vect) {
    // Отключение прерывания компаратора
    Disable_ANA_Comp_Interrupt();

    blink_led(global_mode);

    Clean_ANA_Comp_Flag();
    Enable_ANA_Comp_Interrupt();
}

int main(void) {
    // Инициализация периферии
    PORT_B_Init();
    ANA_Comp_Init();
    Timer_Init();
    PCINT0_Interrupt_Init();

    // Разрешение глобальных прерываний
    sei();

    // Основной цикл программы
    while (1) {}

    return 0;
}

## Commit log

2025-03-13 Added 3D models and designs
    [Аккумуляторная часть платы.dxf, Задняя часть платы.dxf, Основная часть платы.dxf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]
2025-03-13 Added PCB and Electric Schemes
    [Battery.kicad_sch, Charger.kicad_sch, Fotodiode_Sensor.kicad_sch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]
2025-06-07 [Code] Made writing high frequency fuses and fixed custom_delay function
